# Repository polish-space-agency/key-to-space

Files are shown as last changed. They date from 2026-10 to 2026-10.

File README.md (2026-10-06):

<p align="right">
  <b>Polski</b> | <a href="README.en.md">English</a>
</p>

<p align="center">
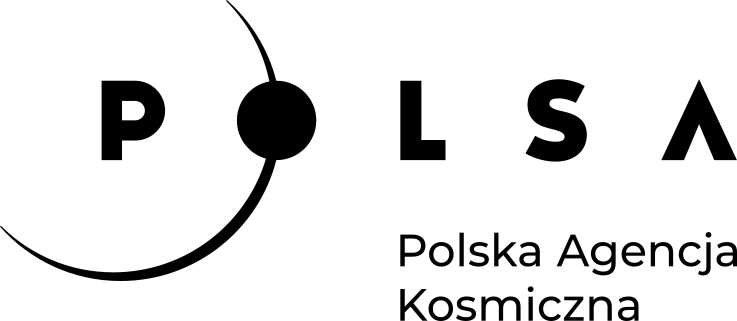
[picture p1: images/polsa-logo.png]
Polska Agencja Kosmiczna
  
</p>

# Klucz do Kosmosu

```
OŚWIADCZENIE LICENCYJNE PROJEKTU

PL: Cała zawartość tego repozytorium, w tym pliki projektowe programu KiCad (schematy i projekty płytek PCB) oraz dokumentacja techniczna, udostępniana jest na licencji:
Creative Commons Uznanie autorstwa - Użycie niekomercyjne - Na tych samych warunkach 4.0 Międzynarodowe (CC BY-NC-SA 4.0).

Pełna treść licencji dostępna jest pod adresem: https://creativecommons.org/licenses/by-nc-sa/4.0/legalcode.txt

WARUNKI SZCZEGÓŁOWE I INTENCJA AUTORA:
1. UŻYTEK NIEKOMERCYJNY: Zezwala się na kopiowanie, modyfikowanie oraz wytwarzanie fizycznych egzemplarzy urządzenia wyłącznie do celów niekomercyjnych, prywatnych, hobbystycznych (np. przez krótkofalowców, majsterkowiczów) oraz statutowych (przez organizacje pozarządowe / NGO).
2. SPECJALNE ZEZWOLENIE DLA PLACÓWEK OŚWIATOWYCH: Oficjalne szkoły, uczelnie wyższe oraz inne placówki dydaktyczne są wyraźnie uprawnione do wytwarzania oraz zlecania produkcji tego urządzenia (w tym zamawiania partii płytek PCB w zewnętrznych przedsiębiorstwach) na własne, wewnętrzne potrzeby edukacyjne i szkoleniowe.
3. OZNACZENIE AUTORA NA PCB (WARUNEK "BY"): Zgodnie z warunkiem Uznania Autorstwa, zabrania się usuwania, modyfikowania lub zakrywania oznaczeń autora (nazwiska, nicku lub logo) umieszczonych na warstwie opisowej (silkscreen) płytki PCB. Każda wyprodukowana płytka musi te oznaczenia zachować w oryginalnej formie.
```

**Dokumentacja techniczna – edukacyjne urządzenie elektroniczne, wersja szkolna**

Projekt powstał na zlecenie Polskiej Agencji Kosmicznej na potrzeby działań edukacyjnych dla misji IGNIS. Realizatorami misji IGNIS byli: Ministerstwo Rozwoju i Technologii, Polska Agencja Kosmiczna i Europejska Agencja Kosmiczna.
Projekt wyprodukowano i rozdano w liczbie 100 000 egzemplarzy, nieodpłatnie do polskich szkół.

Na prośby kierowane do POLSA, projekt udostępniony jest dla hobbystów i wszystkich zainteresowanych niekomercyjnym jego użyciem.

<p align="center">
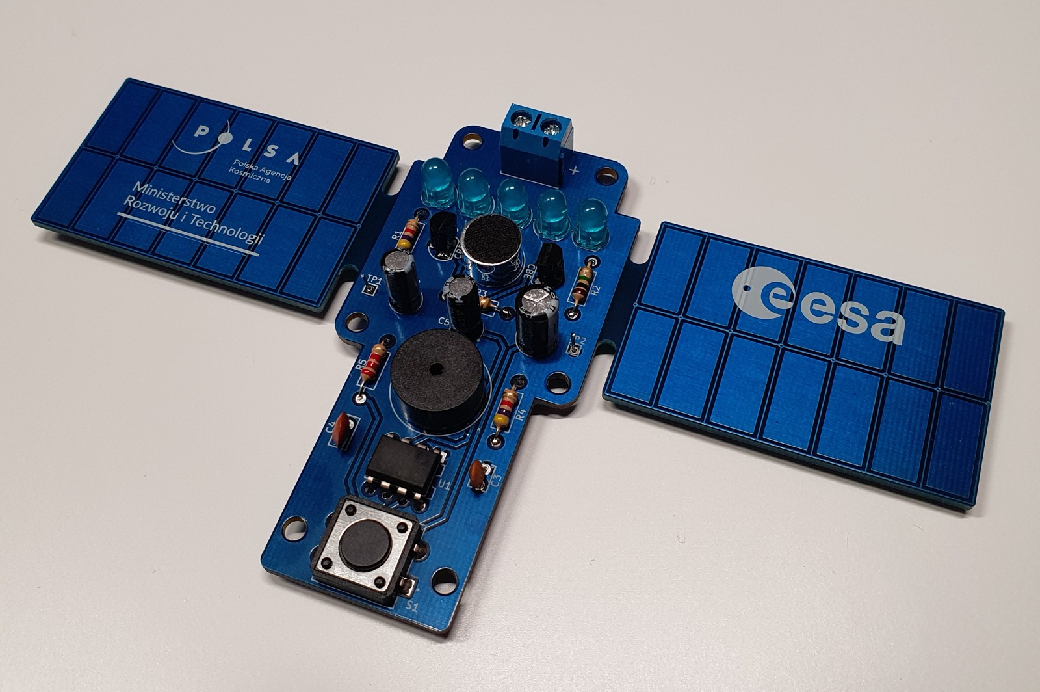
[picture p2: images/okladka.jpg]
Klucz do kosmosu – zmontowane urządzenie
  
</p>

## Spis treści

- [Słownik skrótów](#słownik-skrótów)
- [1. Wprowadzenie](#1-wprowadzenie)
- [2. Specyfikacja techniczna](#2-specyfikacja-techniczna)
- [3. Opis urządzenia](#3-opis-urządzenia)
- [4. Lista komponentów (BOM)](#4-lista-komponentów-bom)
- [5. Testy](#5-testy)
- [6. Informacje dotyczące produkcji](#6-informacje-dotyczące-produkcji)

## Słownik skrótów

| Skrót | Rozwinięcie |
|---|---|
| BOM | Bill of Materials |
| FR | Flame Retardant |
| HAL | Hot Air Leveling |
| ISS | International Space Station |
| LED | Light-Emitting Diode |
| PCB | Printed Circuit Board |
| STEM  | Science, Technology, Engineering, Mathematics |
| THT | Through-Hole Technology |
| USB | Universal Serial Bus |

## 1. Wprowadzenie

Niniejsza dokumentacja techniczna zawiera kluczowe informacje na temat projektu edukacyjnego urządzenia elektronicznego *Klucz do kosmosu*, zaprojektowanego dla Polskiej Agencji Kosmicznej. Urządzenie (płytka PCB z zestawem komponentów do samodzielnego montażu) jest częścią większego programu edukacyjnego promującego naukę STEM i będzie wykorzystywane do nauczania podstaw elektroniki i lutowania w szkołach.

Dokumentacja zawiera specyfikację techniczną, opis budowy i działania, a także informacje przydatne przy ewentualnej produkcji tego urządzenia.

## 2. Specyfikacja techniczna

### 2.1. Wymiary

Płytka PCB w kształcie satelity. Grubość laminatu typowa – 1,57 mm (0,063 cala). Płytka posiada sześć otworów montażowych o średnicy 3,2 mm.

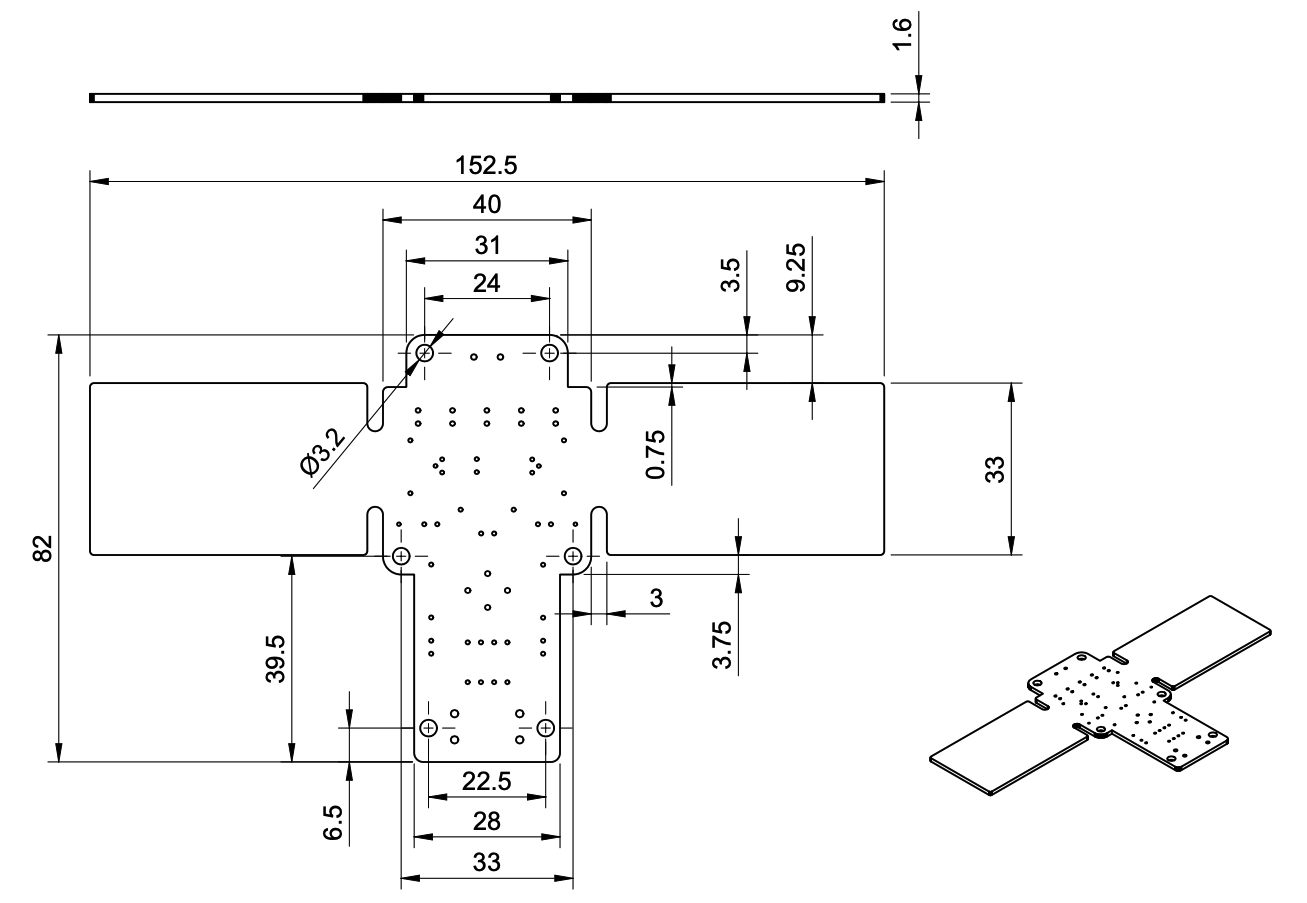
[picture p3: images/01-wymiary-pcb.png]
Rysunek 1: Wymiary płytki PCB


*Rysunek 1: Wymiary płytki PCB*

### 2.2. Montaż

Urządzenie jest przeznaczone do samodzielnego montażu, dlatego zastosowano w nim łatwe do lutowania elementy przewlekane (THT).

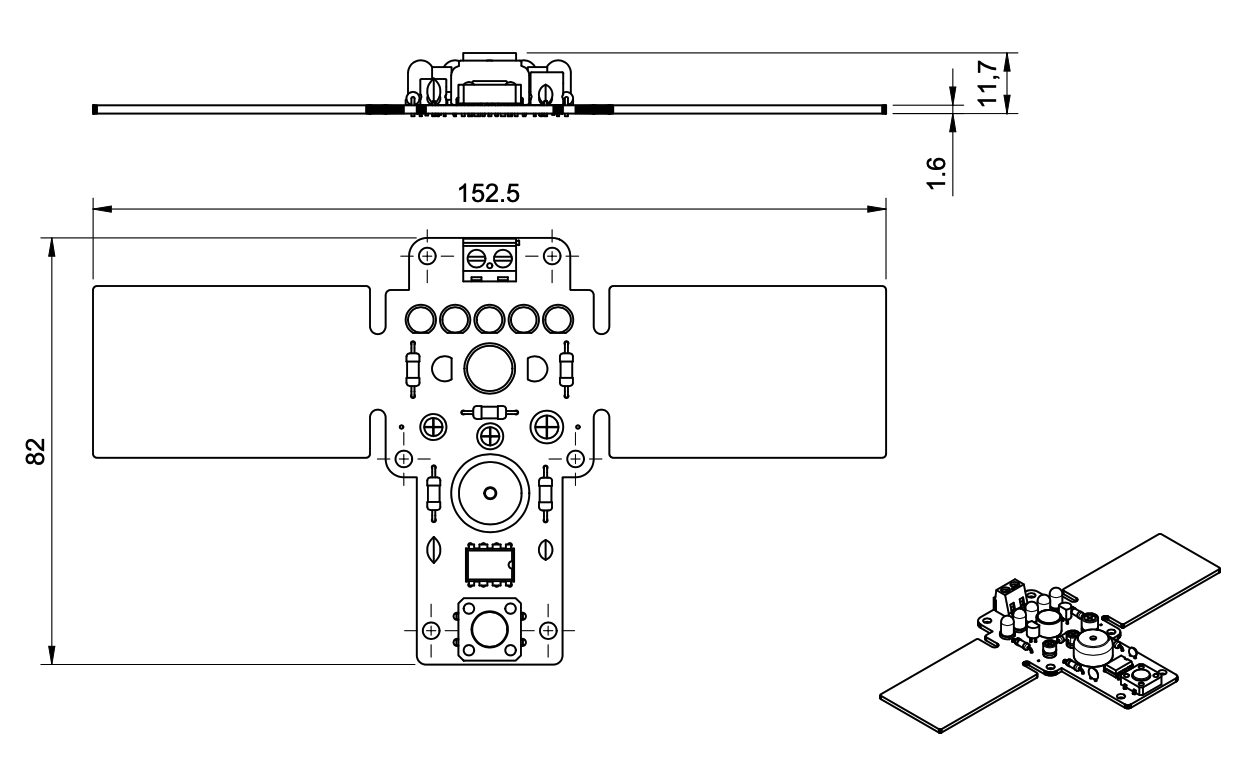
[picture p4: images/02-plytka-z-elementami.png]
Rysunek 2: Płytka z wlutowanymi elementami


*Rysunek 2: Płytka z wlutowanymi elementami*

Całkowita masa urządzenia (PCB z komponentami): około 40 g.

### 2.3. Zasilanie

Układ może być zasilany napięciem stałym z zakresu od 3 V do 9 V. Daje to szeroki wybór źródła zasilania – np. USB (zasilacz, ładowarka, laptop, power bank) lub popularne baterie (1,5 V typu AA lub AAA).

Maksymalny pobór prądu: poniżej 200 mA.

## 3. Opis urządzenia

Urządzenie składa się z dwóch niezależnych analogowych układów elektronicznych realizujących następujące funkcje:

- **klucz telegraficzny** – układ emitujący dźwięk po naciśnięciu przycisku,
- **klaskacz** – układ reagujący na dźwięk świeceniem diod LED.

Projekt wykorzystuje zróżnicowany zestaw elementów elektronicznych, takich jak rezystory, kondensatory, tranzystory, układy scalone, diody LED, przetworniki dźwięku, a także elementy mechaniczne. Ten zróżnicowany zestaw komponentów stanowi cenne narzędzie edukacyjne dla użytkowników, którzy mogą dowiedzieć się o zastosowaniach różnych komponentów, zrozumieć ich działanie i zależności między nimi.

### 3.1. Budowa

#### 3.1.1. Płytka PCB

Zaprojektowana płytka PCB jest dwustronna (dwuwarstwowa), pokryta niebieską maską lutowniczą z opisami od strony elementów. Boczne skrzydła, przypominające panele słoneczne satelity, nie są częścią układu elektronicznego – stanowią jedynie ozdobę i miejsce na logo.

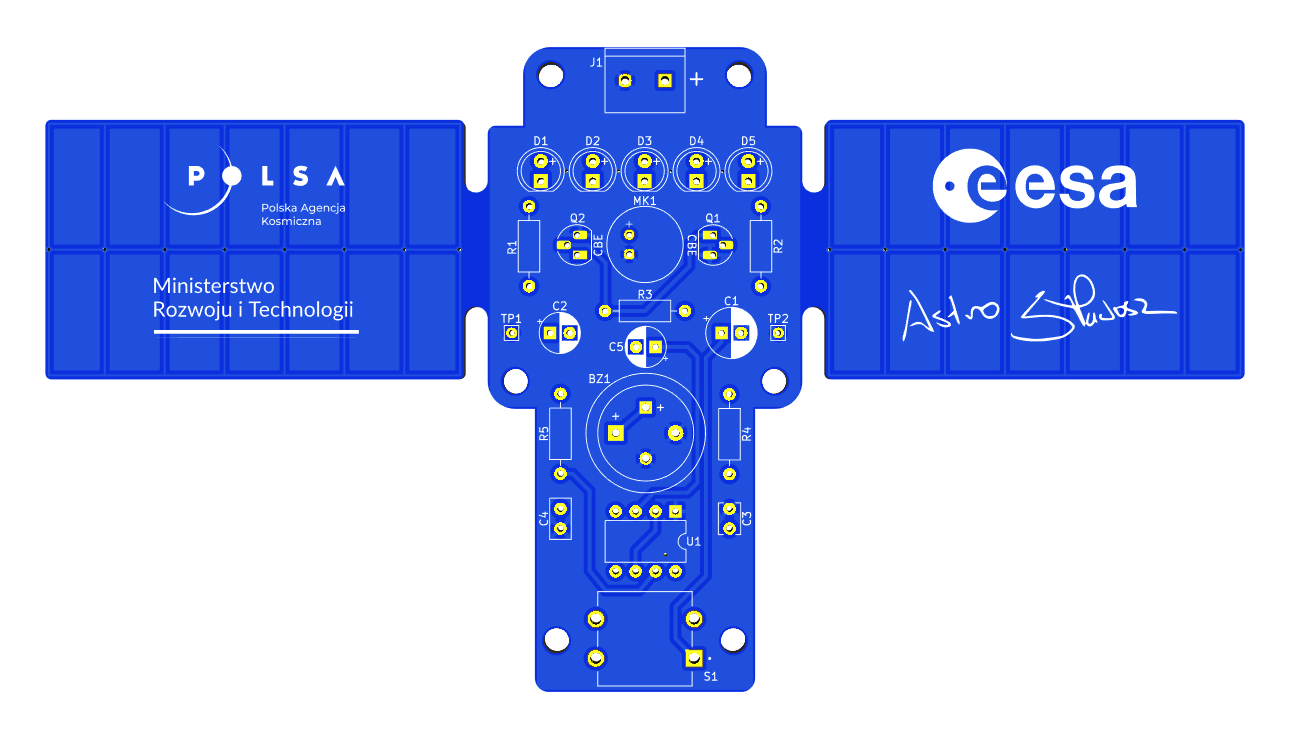
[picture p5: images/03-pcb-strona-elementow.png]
Rysunek 3: Płytka PCB – strona elementów


*Rysunek 3: Płytka PCB – strona elementów*

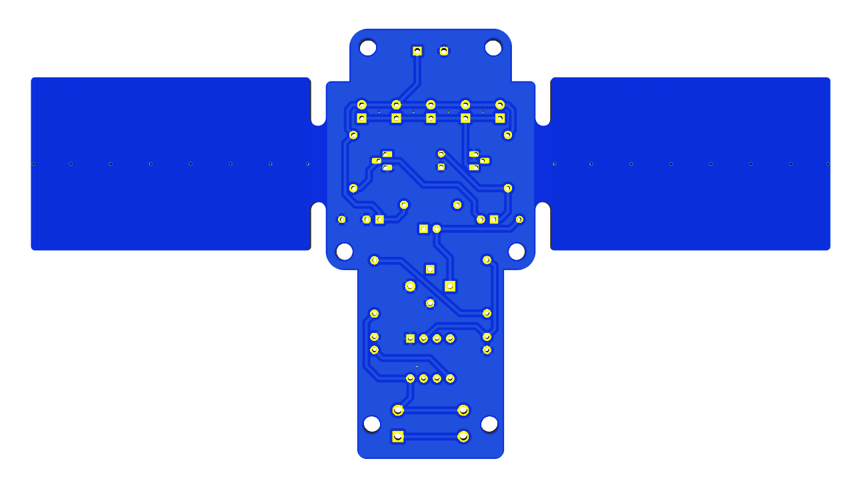
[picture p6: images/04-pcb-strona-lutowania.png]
Rysunek 4: Płytka PCB – strona lutowania


*Rysunek 4: Płytka PCB – strona lutowania*

#### 3.1.2. Rozmieszczenie komponentów

Poniższy rysunek przedstawia wizualizację płytki drukowanej z rozmieszczonymi komponentami i podziałem na układy elektroniczne realizujące określone funkcje.

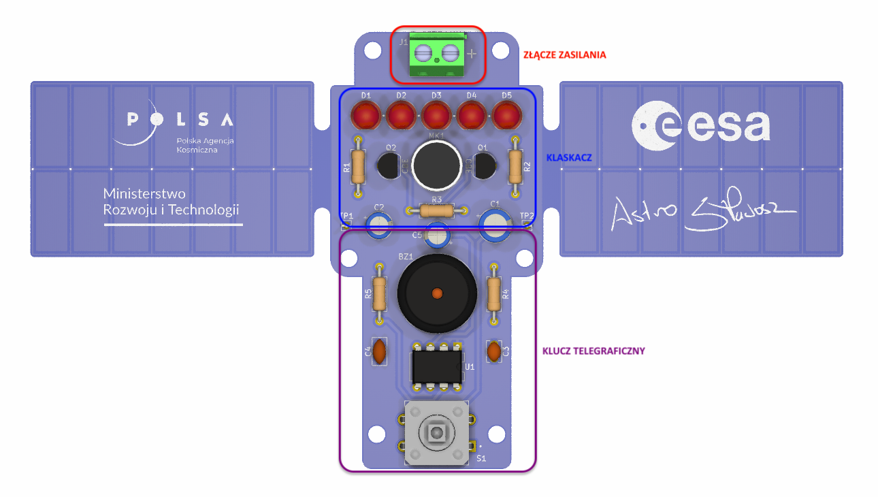
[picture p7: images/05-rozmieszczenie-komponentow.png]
Rysunek 5: Rozmieszczenie komponentów na płytce PCB


*Rysunek 5: Rozmieszczenie komponentów na płytce PCB*

### 3.2. Klucz telegraficzny

Obwód elektroniczny realizujący funkcję klucza telegraficznego składa się z następujących elementów:

- mikroprzełącznik,
- generator astabilny,
- brzęczyk piezoelektryczny.

Po naciśnięciu mikroprzełącznika monostabilnego (S1) włączane jest zasilanie obwodu generatora astabilnego, który generuje zmienny sygnał dla brzęczyka piezoelektrycznego (BZ1). Brzęczyk przetwarza zmienne napięcie elektryczne w sygnał akustyczny.

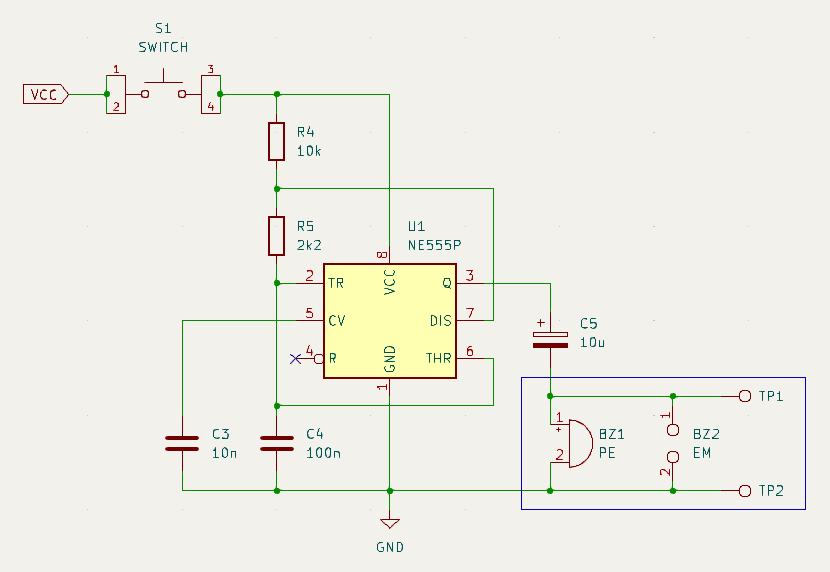
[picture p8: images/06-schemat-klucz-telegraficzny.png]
Rysunek 6: Schemat układu klucza telegraficznego


*Rysunek 6: Schemat układu klucza telegraficznego*

Generator astabilny zbudowany na układzie timera NE555P (U1) to proste, ale wszechstronne rozwiązanie służące do generowania sygnałów prostokątnych o zmiennej częstotliwości i współczynniku wypełnienia. Jego elastyczność, niezawodność i łatwość implementacji czynią go popularnym rozwiązaniem w wielu aplikacjach elektronicznych.

Podczas działania układu kondensator C4 jest cyklicznie ładowany i rozładowywany. Układ NE555P kontroluje ten proces i zmienia stan logiczny na wyjściu Q, generując okresowy przebieg prostokątny.

Kondensator C3 służy do blokowania szybkich zmian napięć odniesienia podawanych na układ U1 z dzielnika.

Częstotliwość generowanego przebiegu można wyznaczyć zgodnie z zależnością:

$$f = \frac{1{,}44}{(R_4 + 2R_5)\,C_4}$$

Współczynnik wypełnienia generowanego przebiegu:

$$D = \frac{R_4 + R_5}{R_4 + 2R_5}$$

Wartości rezystancji R4 i R5 oraz pojemność kondensatora C4 mają bezpośredni wpływ na częstotliwość i cykl pracy generowanego przebiegu:

- zwiększenie C4 zwiększy czas cyklu, a tym samym zmniejszy częstotliwość,
- zwiększenie R4 zwiększy czas trwania stanu wysokiego (*Time High*), ale nie wpłynie na czas trwania stanu niskiego (*Time Low*),
- zwiększenie R5 zwiększy czas trwania stanu wysokiego (*Time High*), zwiększy czas trwania stanu niskiego (*Time Low*) i zmniejszy cykl pracy (do minimum 50%).

Generowany sygnał podawany na brzęczyk można obserwować, podłączając oscyloskop do punktów pomiarowych TP1 i TP2 (masa) na płytce drukowanej.

Poniższy rysunek przedstawia obliczenia wykonane dla wartości elementów użytych w obwodzie.

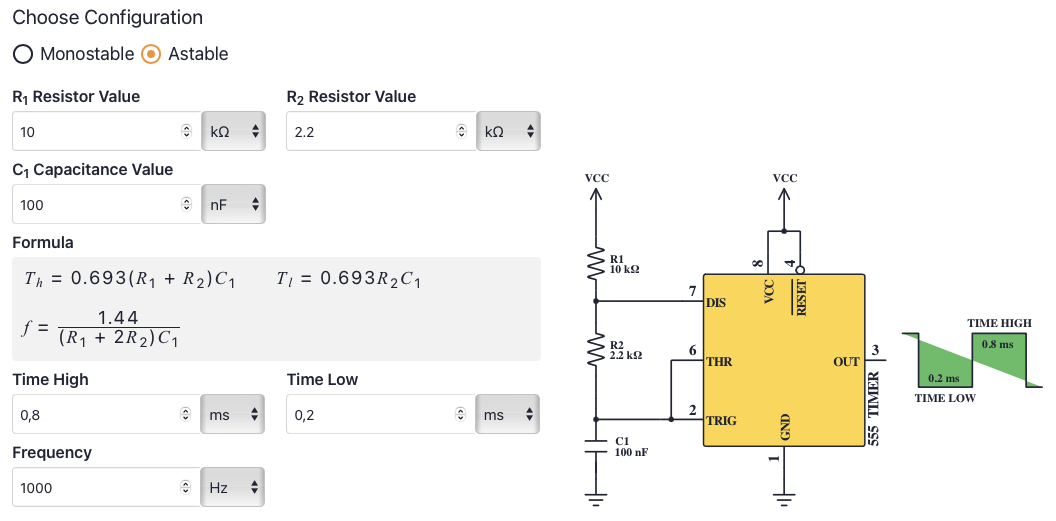
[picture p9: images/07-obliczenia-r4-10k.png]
Rysunek 7: Wyliczone parametry przebiegu dla R4=10kΩ, R5=2.2kΩ i C4=100nF


*Rysunek 7: Wyliczone parametry przebiegu dla R4 = 10 kΩ, R5 = 2,2 kΩ i C4 = 100 nF*

Parametry rzeczywistego przebiegu mogą się różnić od wyliczonych ze względu na tolerancję wartości komponentów zastosowanych do budowy układu.

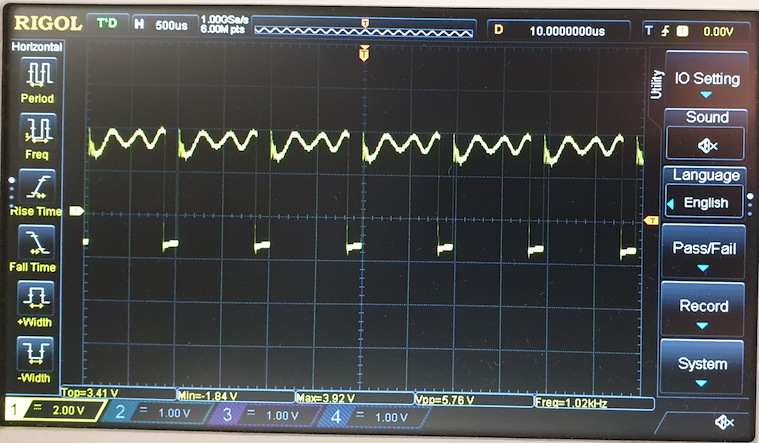
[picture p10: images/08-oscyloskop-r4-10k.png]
Rysunek 8: Rzeczywisty przebieg obserwowany na oscyloskopie


*Rysunek 8: Rzeczywisty przebieg obserwowany na oscyloskopie*

Zmiana rezystancji R4 na 15 kΩ spowoduje zmniejszenie częstotliwości generowanego przebiegu.

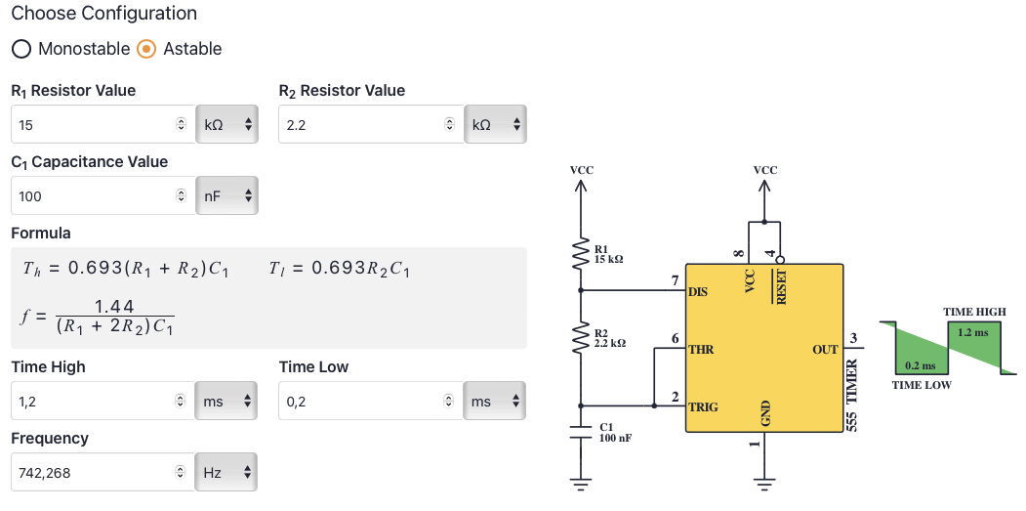
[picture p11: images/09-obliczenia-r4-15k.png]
Rysunek 9: Zmiana parametrów po zwiększeniu rezystancji R4


*Rysunek 9: Zmiana parametrów po zwiększeniu rezystancji R4*

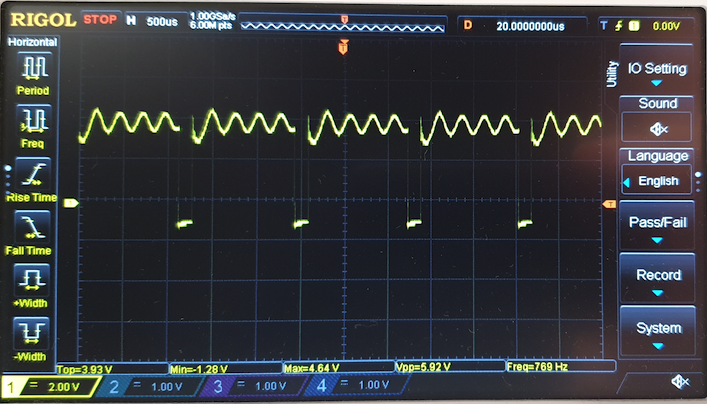
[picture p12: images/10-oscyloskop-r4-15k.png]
Rysunek 10: Przebieg po zwiększeniu rezystancji R4


*Rysunek 10: Przebieg po zwiększeniu rezystancji R4*

Zamiana miejscami rezystancji R4 i R5 oraz zmniejszenie pojemności C4 do 22 nF powoduje zwiększenie częstotliwości generowanego przebiegu i zmniejszenie współczynnika wypełnienia. Może to poprawić brzmienie brzęczyka.

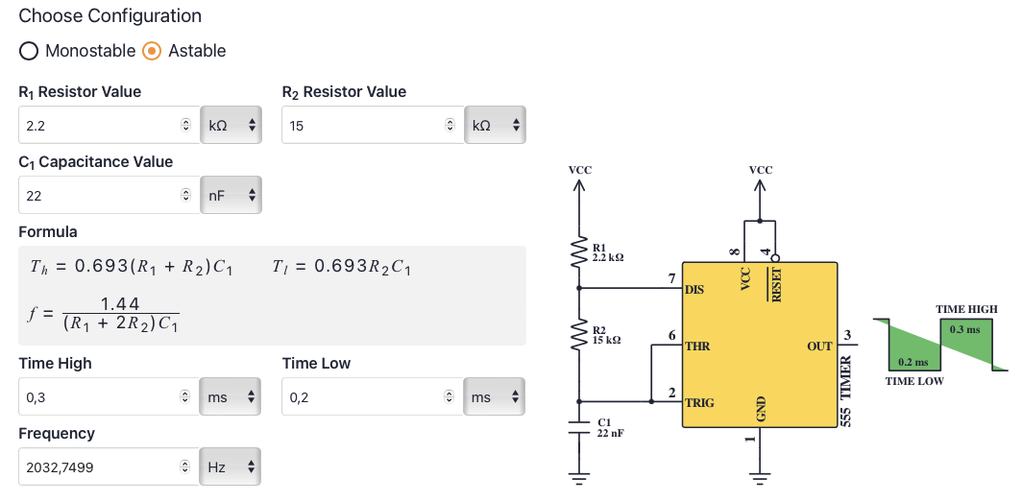
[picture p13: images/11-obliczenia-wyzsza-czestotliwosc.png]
Rysunek 11: Zwiększenie częstotliwości generowanego przebiegu


*Rysunek 11: Zwiększenie częstotliwości generowanego przebiegu*

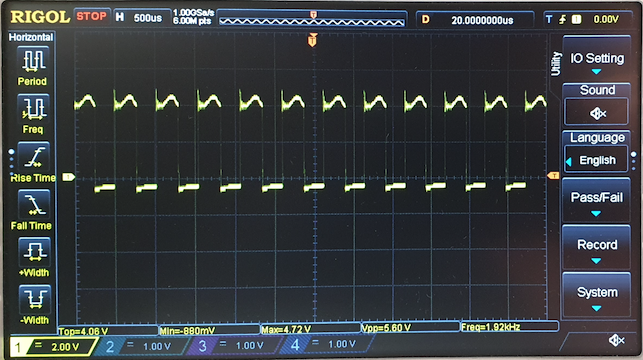
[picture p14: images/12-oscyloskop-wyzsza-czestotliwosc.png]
Rysunek 12: Rzeczywisty przebieg po zwiększeniu częstotliwości


*Rysunek 12: Rzeczywisty przebieg po zwiększeniu częstotliwości*

Zamiast brzęczyka piezoelektrycznego można zastosować brzęczyk elektromagnetyczny (również bez wbudowanego generatora). Na płytce są otwory dostosowane do mniejszego rastra wyprowadzeń i średnicy tego typu komponentu.

### 3.3. Klaskacz

W układzie realizującym funkcjonalność klaskacza można wyróżnić:

- mikrofon z układem przedwzmacniacza,
- wzmacniacz sygnału,
- wskaźnik zbudowany z diod LED.

Mikrofon reaguje na zmiany ciśnienia akustycznego w otoczeniu, generując zmienne napięcie wyjściowe proporcjonalne do natężenia dźwięku. Sygnał ten jest wzmacniany i wykorzystany do wysterowania diod LED.

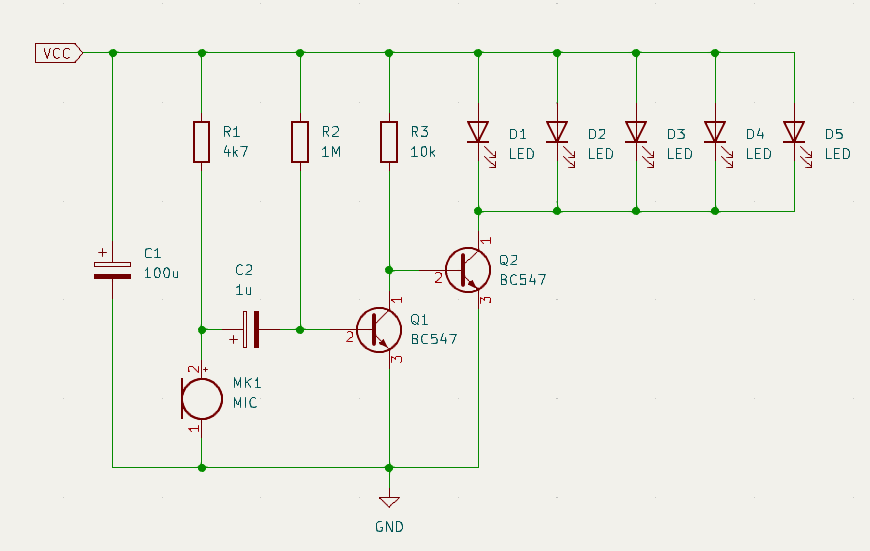
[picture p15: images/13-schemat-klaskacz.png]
Rysunek 13: Schemat układu „klaskacza”


*Rysunek 13: Schemat układu „klaskacza”*

Zastosowany mikrofon elektretowy (MK1) charakteryzuje się niewielkimi rozmiarami, niską impedancją wyjściową i szerokim zakresem częstotliwości. Ten typ mikrofonu posiada wbudowany przedwzmacniacz w postaci tranzystora polowego. Tranzystor ten musi być zasilany z zewnętrznego źródła napięcia poprzez rezystor polaryzujący R1, który pełni również rolę obciążenia. Wartość tego rezystora jest dobierana tak, żeby zapewnić odpowiednie napięcie pracy mikrofonu, i ma również wpływ na wzmocnienie. Kondensator C2 na wyjściu służy do eliminacji składowej stałej.

Tranzystory Q1 i Q2 służą do wzmacniania sygnału z mikrofonu i sterowania diodami LED. Zmiany sygnału mikrofonu powodują zmiany prądu kolektora tranzystora Q2, zmieniając w ten sposób intensywność diod LED. Rezystor R3 może być używany do regulacji jasności diod LED.

## 4. Lista komponentów (BOM)

### 4.1. Elementy montowane na płytce PCB

Wszystkie elementy do montażu przewlekanego (THT).

| Element | Wartość/typ | Opis | Obudowa | Symbol – przykład |
|---|---|---|---|---|
| R1 | 4.7kΩ[^1] | Rezystor węglowy, 0.25W, ±5% | Osiowa, Ø2.3x6mm | CF1/4W-4K7 |
| R2 | 1MΩ | Rezystor węglowy, 0.25W, ±5% | Osiowa, Ø2.3x6mm | CF1/4W-1M |
| R3 | 10kΩ[^2] | Rezystor węglowy, 0.25W, ±5% | Osiowa, Ø2.3x6mm | CF1/4W-10K |
| R4 | 10kΩ[^3] | Rezystor węglowy, 0.25W, ±5% | Osiowa, Ø2.3x6mm | CF1/4W-10K |
| R5 | 2.2kΩ | Rezystor węglowy, 0.25W, ±5% | Osiowa, Ø2.3x6mm | CF1/4W-2K2 |
| C3 | 10nF | Kondensator ceramiczny, 50V | 2.54mm | CC-10N |
| C4 | 100nF[^4] | Kondensator ceramiczny, 50V | 2.54mm | CC-100N |
| C1 | 100µF | Kondensator elektrolityczny, 25V | Ø6x11mm, 2.5mm | EWH1EV101E11OT |
| C2 | 1µF | Kondensator elektrolityczny, 50V | Ø5x11mm, 2.5mm | EWH1HM010D11X25T |
| C5 | 10µF | Kondensator elektrolityczny, 50V | Ø5x11mm, 2.5mm | EWH1HM100D11X25T |
| U1 | NE555P | Układ scalony, timer | DIP8 | NE555P |
| Q1, Q2 | BC547B[^5] | Tranzystor bipolarny NPN | TO92 | BC547B |
| D1..D5 | | Dioda LED, dyfuzyjna, niebieska, jasność do 1000mcd | 5mm, czoło wypukłe | L-7113QBDL-D |
| MK1[^6] | | Mikrofon elektretowy, 1..10V, 0.5mA, -44dB (min.) | Ø9.7mm, 2.5mm | LD-MC-9765P |
| BZ1 | | Brzęczyk piezoelektryczny bez generatora, 1..10V, 1mA | Ø13.8x6.8mm, 7.6mm | AT-1438-TWT-R |
| S1 | | Mikroprzełącznik monostabilny | 12x12x4.3mm | TACT-24N |
| J1 | | Złącze śrubowe, kątowe 90º, dwutorowe | 5.08mm | 282837-2 lub TB-5.08-P-2P/BL |

Dodatkowe elementy dołączane do zestawu (do eksperymentów, niemontowane na stałe):

| Element | Zamiennik dla | Liczba sztuk |
|---|:---:|:---:|
| Rezystor 4.7kΩ | R3 | 1 |
| Rezystor 15kΩ | R3, R4, R5 | 2 |
| Rezystor 30kΩ | R3 | 1 |
| Kondensator ceramiczny 22nF | C4 | 1 |

[^1]: Alternatywnie 10kΩ w zależności od czułości zastosowanego mikrofonu – zwiększenie rezystancji może poprawić działanie układu klaskacza.
[^2]: Zmiana rezystancji R3 w zależności od napięcia zasilania układu powoduje zmianę intensywności świecenia diod LED – przy wyższym napięciu zasilania zwiększenie rezystancji zmniejszy intensywność świecenia diod LED i może w niektórych przypadkach poprawić brzmienie brzęczyka (proponowane dodatkowe rezystory 4.7kΩ, 15kΩ i 30kΩ).
[^3]: Do zestawu powinny być dodane inne wartości rezystorów R4 i R5, aby umożliwić eksperymenty związane ze zmianą parametrów generowanego przebiegu (proponowany dodatkowy rezystor 15kΩ).
[^4]: Podobnie jak rezystory R4 i R5, pojemność C4 ma również bezpośredni wpływ na parametry generowanego przebiegu, więc do zestawu powinna być dodana również inna wartość pojemności (np. 22nF).
[^5]: Układ został przetestowany również z innymi typami tranzystorów NPN (BC183, BC546, BC548, BC549, BC550).
[^6]: Najlepiej sprawdził się mikrofon OEM, dla którego nie udało się ustalić symbolu i nazwy producenta, a także uzyskać karty katalogowej – w tabeli podany został komponent alternatywny zastosowany w wersji dla ISS. Mikrofon OEM jest dostępny pod kodem UCC-00740.

### 4.2. Komponenty dodatkowe

Proponowane elementy dodatkowe związane z wyborem źródła zasilania:

- koszyk na 2 lub 3 baterie (typu AA lub AAA) z przewodami – w zestawie 1 szt. (koszyk na 2 baterie AAA),
- wtyk USB typ A na przewód do lutowania – 1 szt.

Koszyk na baterie lub przygotowany kabel z wtyczką USB należy podłączyć do złącza zaciskowego śrubowego na płytce PCB (oznaczonego symbolem J1) z zachowaniem odpowiedniej polaryzacji.

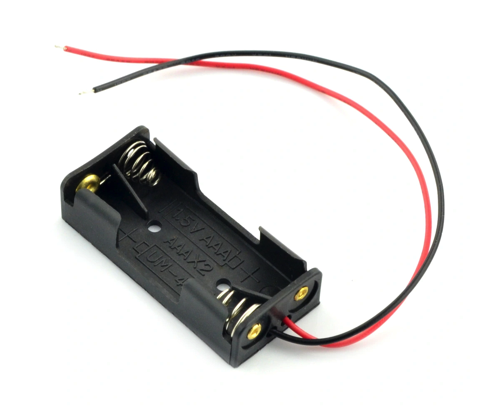
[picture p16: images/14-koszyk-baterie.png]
Rysunek 14: Koszyk na baterie 2xAAA
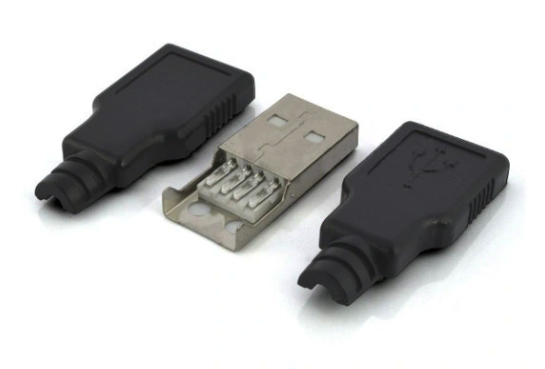
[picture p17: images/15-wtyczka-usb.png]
Rysunek 15: Wtyczka USB z obudową
|  |  |
|:---:|:---:|
| *Rysunek 14: Koszyk na baterie 2xAAA* | *Rysunek 15: Wtyczka USB z obudową* |

Opcjonalne elementy montażowe:

- kołki dystansowe poliamidowe (M3, 10mm) – 6 szt.,
- śruby nylonowe (M3, 6mm) – 6 szt.

## 5. Testy

### 5.1. Pobór prądu

Urządzenie charakteryzuje się niskim zużyciem energii. Testy z wykorzystaniem modułu analizy parametrów zasilania (*Power Profiler Kit*) jako źródła zasilania wykazały, że podczas normalnej pracy przy napięciu zasilania 5 V szczytowe wartości prądu nie przekraczają 150 mA.

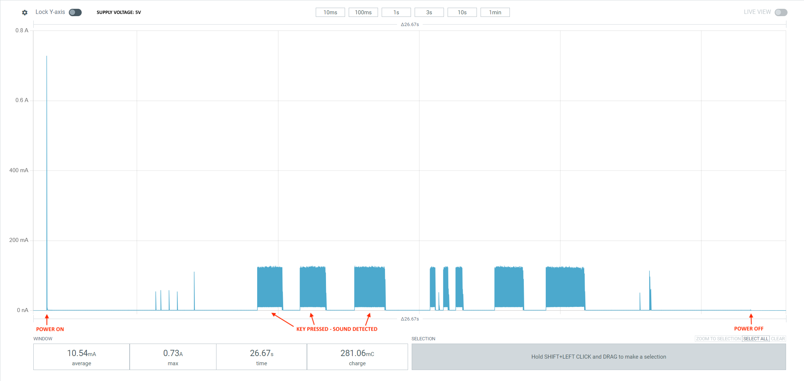
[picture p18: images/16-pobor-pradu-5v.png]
Rysunek 16: Pobór prądu podczas pracy urządzenia przy napięciu zasilania 5V


*Rysunek 16: Pobór prądu podczas pracy urządzenia przy napięciu zasilania 5 V*

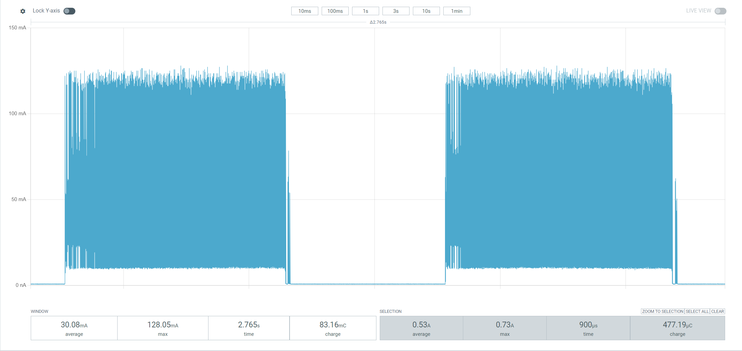
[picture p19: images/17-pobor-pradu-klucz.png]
Rysunek 17: Pobór prądu podczas używania klucza telegraficznego


*Rysunek 17: Pobór prądu podczas używania klucza telegraficznego*

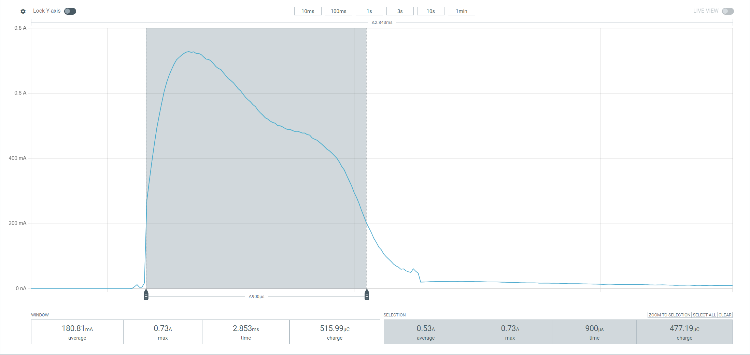
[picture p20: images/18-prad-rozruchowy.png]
Rysunek 18: Prąd rozruchowy w chwili uruchomienia urządzenia


*Rysunek 18: Prąd rozruchowy w chwili uruchomienia urządzenia*

## 6. Informacje dotyczące produkcji

### 6.1. Płytka PCB – specyfikacja techniczna

| Parametr | Wartość |
|---|---|
| Rodzaj laminatu | FR-4 |
| Wymiary zewnętrzne płytki | 153x82mm (1.26dm²) |
| Grubość laminatu bazowego | 1.55mm |
| Liczba warstw | 2 |
| Grubość miedzi | 35µm (1oz) |
| Liczba otworów na płytce | 58 + 6 montażowych |
| Metalizacja otworów | Tak |
| Maska lutownicza (soldermaska) | Dwustronna w kolorze niebieskim |
| Cynowanie | HAL |
| Nietypowy kształt płytki | Tak |
| Frezowanie płytki i otworów | Tak |
| Opis (silkscreen) | Jednostronny w kolorze białym |

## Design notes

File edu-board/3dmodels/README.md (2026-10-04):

Zalecenia do druku 3D:

* Materiał: PLA
* Wysokość warstwy drukowanej: 0,2 mm
* Obrysy: minimum 2
* Materiał podporowy: wymagany
* Wypełnienie: 20 %

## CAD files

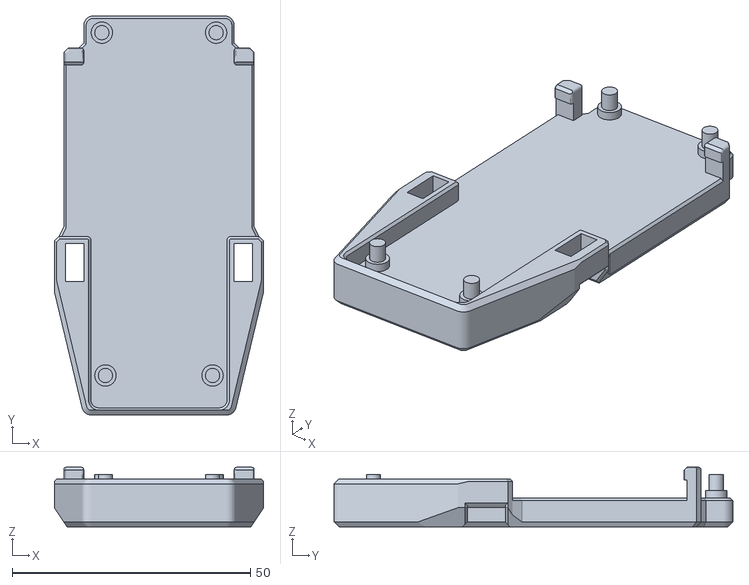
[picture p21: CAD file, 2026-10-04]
3d-prints/edu-board-back-shell.stl
44.0 x 83.8 x 12.5

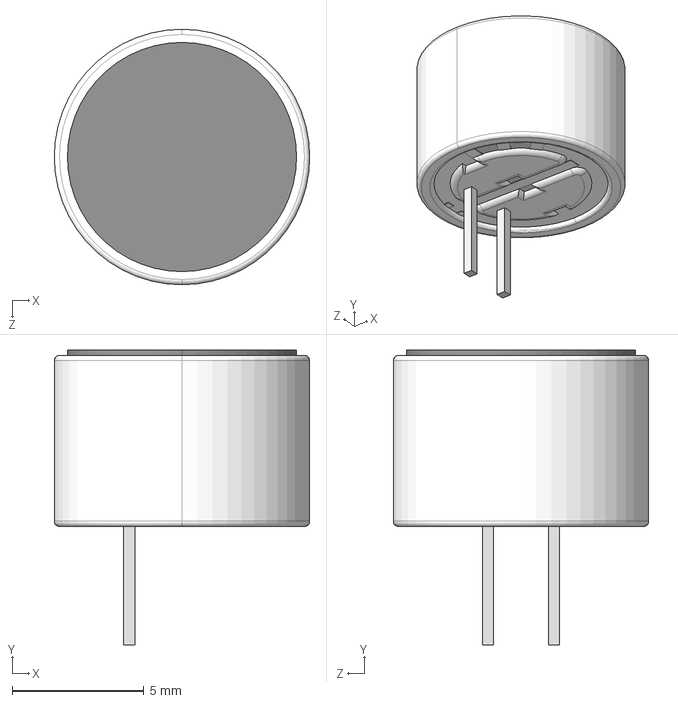
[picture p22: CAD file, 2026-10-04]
edu-board/3dmodels/CUI_CMA-6542PF.step
9.70 x 11.2 x 9.70 mm

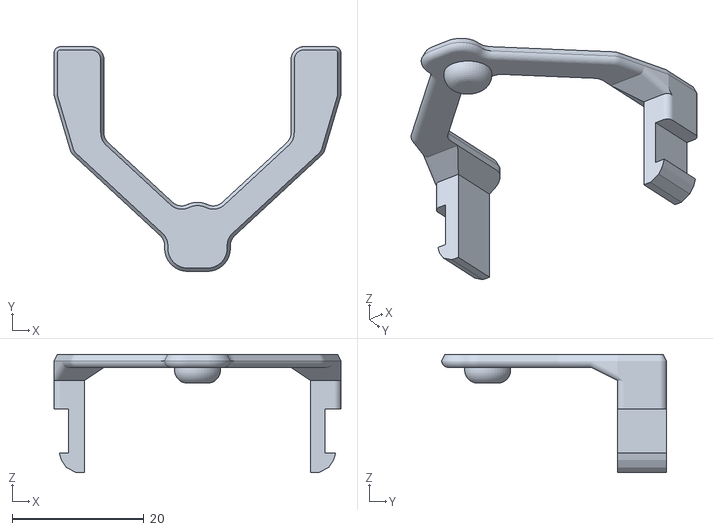
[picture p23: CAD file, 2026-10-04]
3d-prints/edu-board-key-lever.stl
43.6 x 34.2 x 18.0

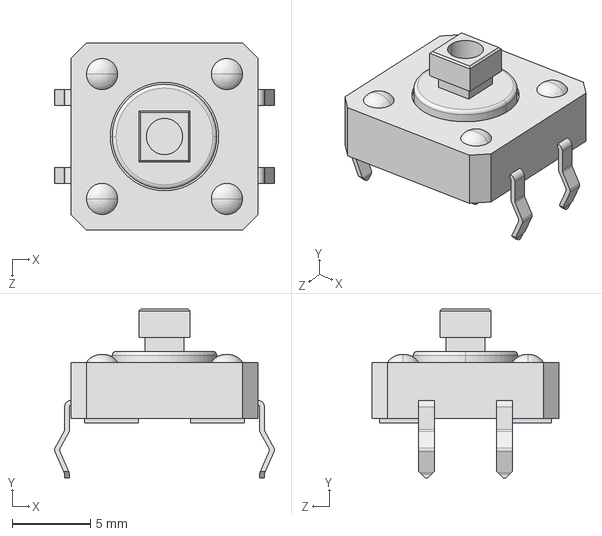
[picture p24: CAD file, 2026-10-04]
edu-board/3dmodels/TL1100F160Q.step
14.1 x 10.8 x 12.0 mm

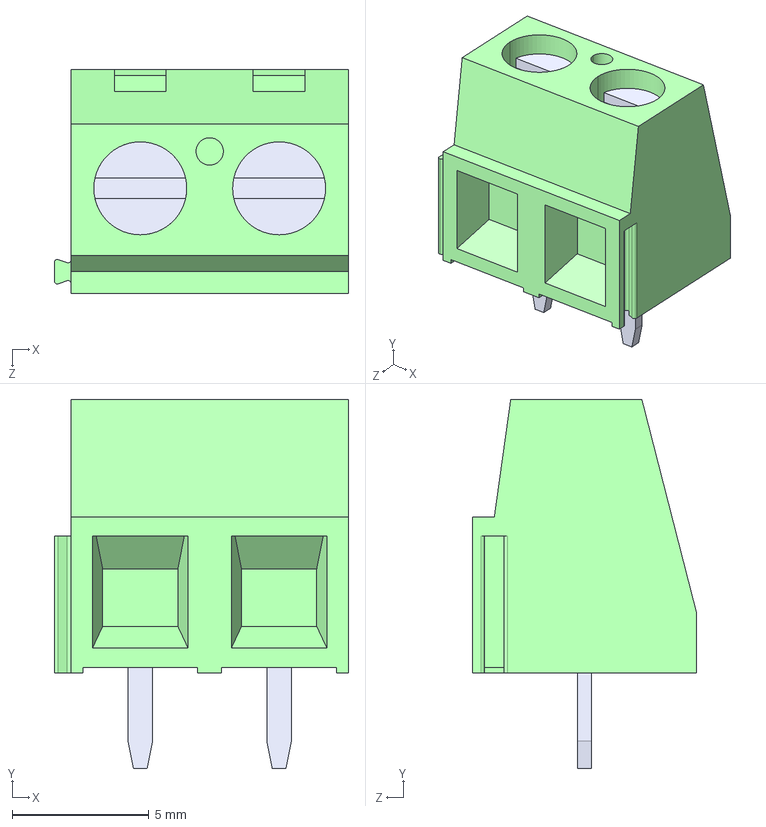
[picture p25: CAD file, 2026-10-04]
edu-board/3dmodels/282837-2.step
10.8 x 13.5 x 8.20 mm

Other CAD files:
3d-prints/edu-board-back-shell.obj
3d-prints/edu-board-key-lever.obj

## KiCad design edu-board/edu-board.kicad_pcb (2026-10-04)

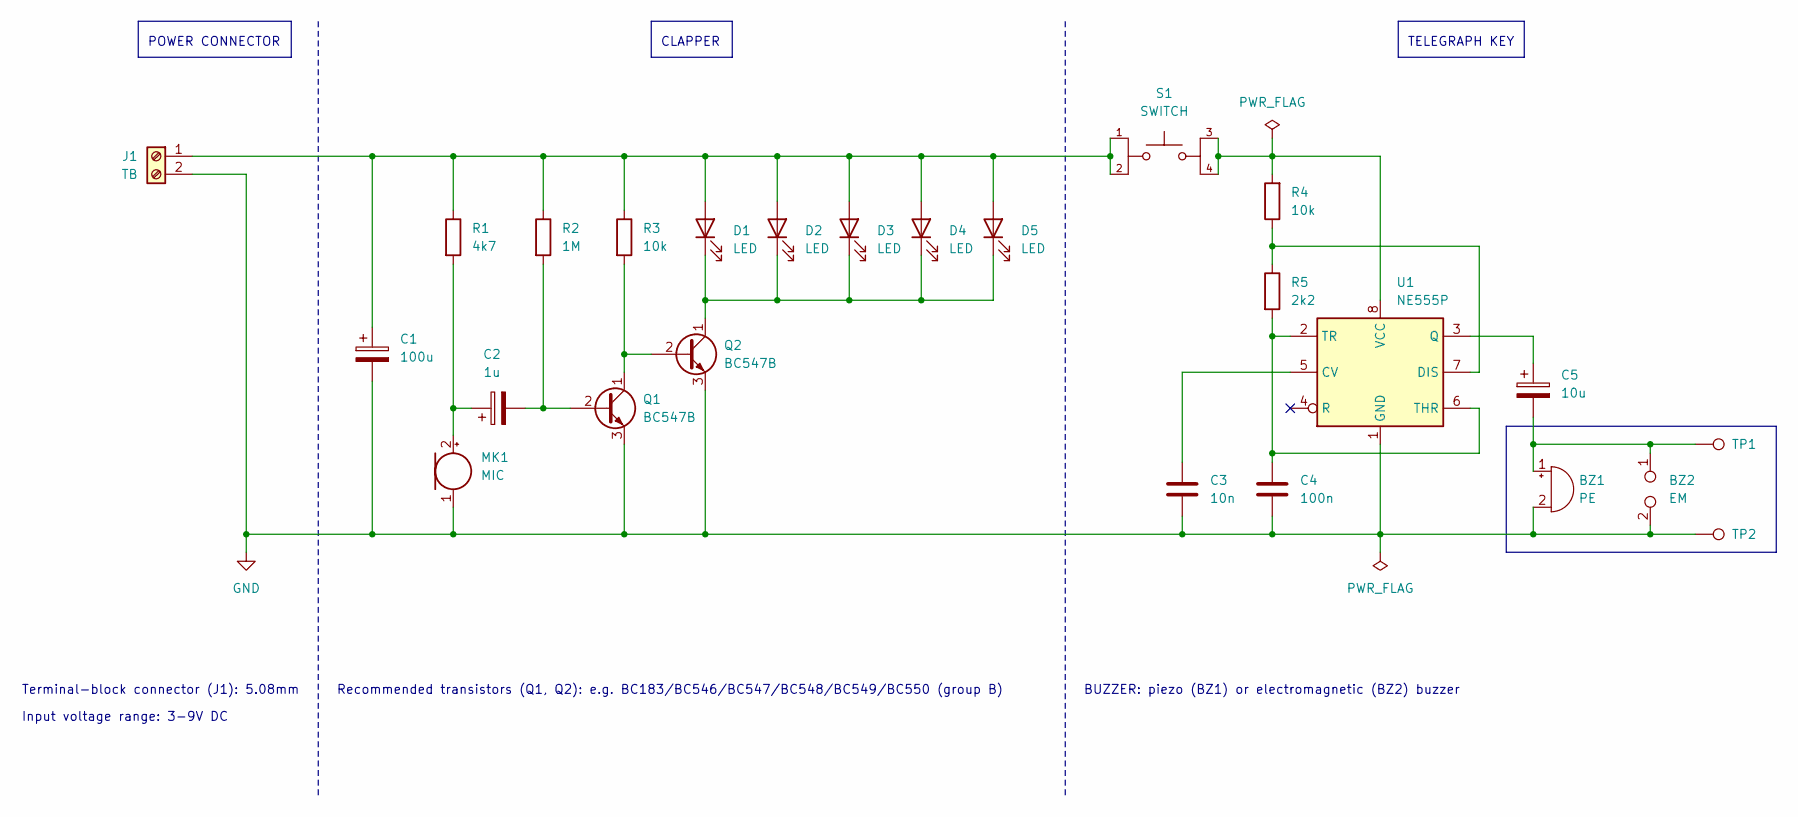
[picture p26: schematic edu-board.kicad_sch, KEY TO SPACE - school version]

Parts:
BZ1: PE; Buzzer_15x7.5RM7.6
BZ2: EM; MagneticBuzzer_ProSignal_ABT-410-RC
C1: 100u; CP_Radial_D6.3mm_P2.50mm
C2: 1u; CP_Radial_D5.0mm_P2.50mm
C3: 10n; C_Disc_D3.8mm_W2.6mm_P2.50mm
C4: 100n; C_Disc_D5.0mm_W2.5mm_P2.50mm
C5: 10u; CP_Radial_D5.0mm_P2.50mm
D1, D2, D3, D4, D5: LED; LED_D5.0mm
J1: TB; TE_282837-2
MK1: MIC; CUI_CMA-6542PF
Q1, Q2: BC547B; TO-92_HandSolder
R1: 4k7; R_Axial_DIN0207_L6.3mm_D2.5mm_P10.16mm_Horizontal
R2: 1M; R_Axial_DIN0207_L6.3mm_D2.5mm_P10.16mm_Horizontal
R3, R4: 10k; R_Axial_DIN0207_L6.3mm_D2.5mm_P10.16mm_Horizontal
R5: 2k2; R_Axial_DIN0207_L6.3mm_D2.5mm_P10.16mm_Horizontal
S1: SWITCH; SW_TL1100F160Q; PARTREV D
TP1, TP2: TestPoint; PinHeader_1x01_P2.54mm_Vertical
U1: NE555P; DIP-8_W7.62mm

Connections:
GND: BZ1.2 (+), BZ2.2, C1.2, C3.2, C4.2, J1.2, MK1.1 (-), Q1.3 (E), Q2.3 (E), TP2.1, U1.1 (GND)
unnamed: R4.2, S1.3, S1.4, U1.8 (VCC)
unnamed: BZ1.1 (-), BZ2.1, C5.2, TP1.1
unnamed: C1.1, D1.2 (A), D2.2 (A), D3.2 (A), D4.2 (A), D5.2 (A), J1.1, R1.1, R2.1, R3.1, S1.1, S1.2
unnamed: D1.1 (K), D2.1 (K), D3.1 (K), D4.1 (K), D5.1 (K), Q2.1 (C)
unnamed: C2.1, MK1.2 (+), R1.2
unnamed: C2.2, Q1.2 (B), R2.2
unnamed: Q1.1 (C), Q2.2 (B), R3.2
unnamed: C3.1, U1.5 (CV)
unnamed: R4.1, R5.1, U1.7 (DIS)
unnamed: C5.1, U1.3 (Q)
unnamed: C4.1, R5.2, U1.2 (TR), U1.6 (THR)

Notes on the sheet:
POWER CONNECTOR
BUZZER: piezo (BZ1) or electromagnetic (BZ2) buzzer
Input voltage range: 3-9V DC
Terminal-block connector (J1): 5.08mm
Recommended transistors (Q1, Q2): e.g. BC183/BC546/BC547/BC548/BC549/BC550 (group B)
TELEGRAPH KEY
CLAPPER

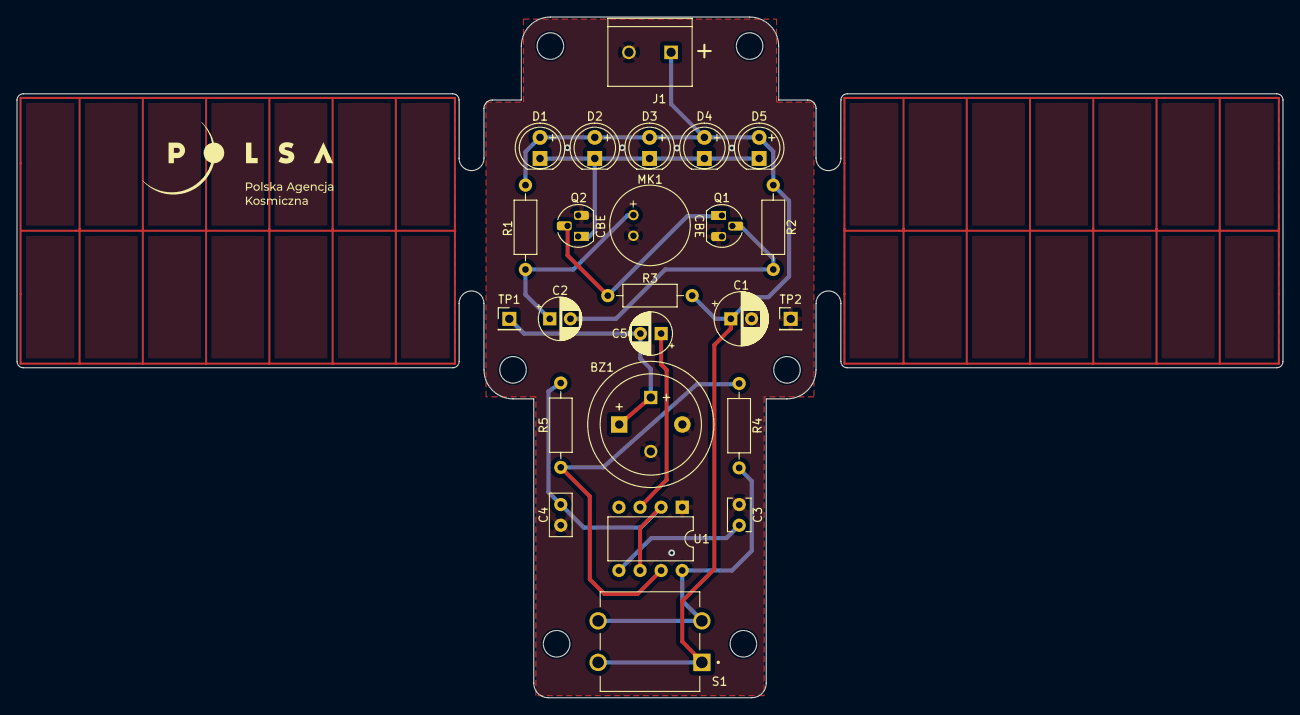
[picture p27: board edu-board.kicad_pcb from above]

Board: 2 copper layers, 152.5 x 82.0 mm, 25 parts (0 on the bottom side), 12 nets.

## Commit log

2026-10-04 Add 3D printing recommendations to README.md
2026-10-06 Revise part numbers in PCB components list
    Updated part numbers in the components table for clarity.
